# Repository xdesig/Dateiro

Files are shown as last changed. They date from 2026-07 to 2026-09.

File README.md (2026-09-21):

# Dateiro - Datalogger e visualización
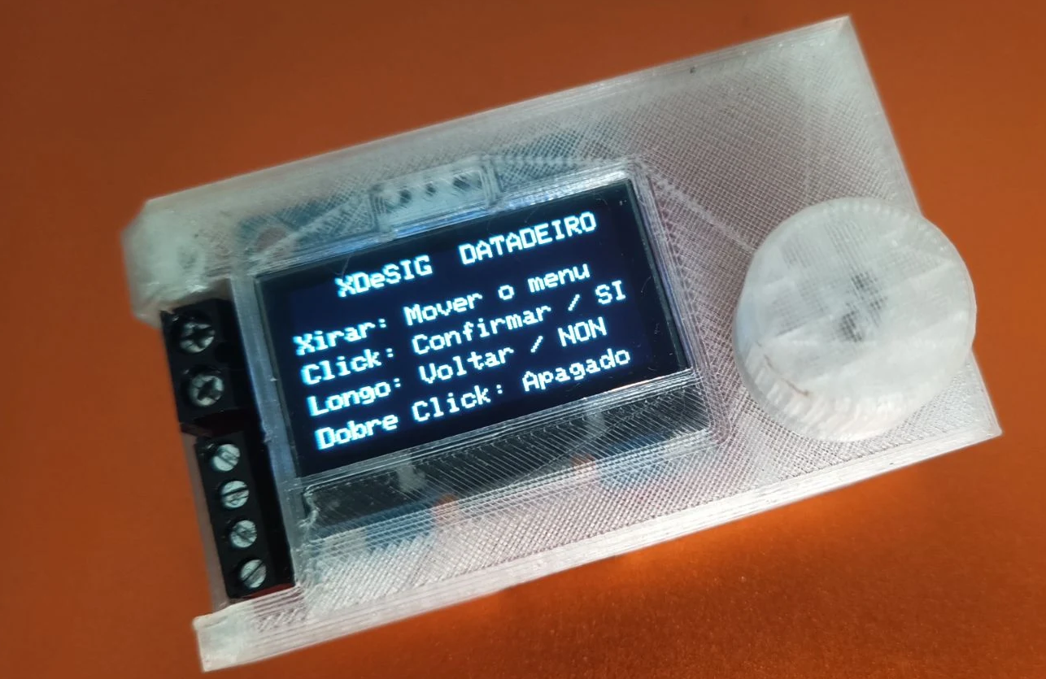
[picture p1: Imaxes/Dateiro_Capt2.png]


> [!NOTE]
> Documentation in Galego 
> [traductor](https://tradutorgaio.xunta.gal/TradutorPublico/traducir/index)

**Dateiro** e un sistema de adquisicion, visualizacion e rexistro de datos (datalogger) deseñado arredor do microcontrolador **ESP32-C3 SuperMini**.
O dispositivo permite a medicion de voltaxe diferencial, corrente e voltaxe de bus, mostrando un grafico en tempo real (modo osciloscopio) nunha pantalla e almacenando os datos en ficheiros `.CSV`
dentro duna tarxeta MicroSD.

---

## Caracteristicas do Firmware

### 1. Gráfica en Tempo Real
- **Buffer Circular:** Mantén un historico de 128 puntos para debuxar a onda na pantalla OLED a intervalos de 50ms (refresh de 20 Hz).
- **Escalado e Grade:** Debuxo de grade de puntos para escala visual e axuste automatico de rango (hasta 16V en modo diferencial e ata 1000mA en modo INA219).

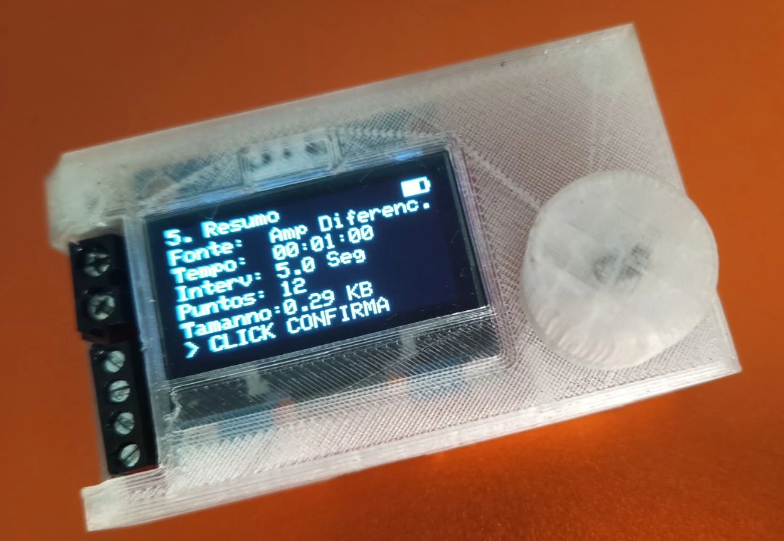
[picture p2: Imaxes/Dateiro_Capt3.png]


### 2. Datalogger Automático (Ficheiros CSV)
- **Nomenclatura Automática:** Crea ficheiros secuenciais no directorio raiz da tarxeta SD (`/DAT_001.CSV`, `/DAT_002.CSV`, etc.).
- **Modos de Mostraxe:**
  - **Por Intervalo:** Define o tempo entre mostras en segundos (ex: cada 5s).
  - **Por Cantidade de Puntos:** Distribue un numero fixo de puntos ao longo do tempo total configurado.
- **Formato do CSV:** Encabezado dinamico dependendo da orixe de datos (`Tempo_ms,Diferencial_V` ou `Tempo_ms,Corrente_mA`).

### 3. Navegación
- Interface baseada nun **Encoder Rotatorio** con descodificacion por matriz de estados (anti-rebotes por interruptor de hardware/software).
- **Xestion de Clicks:**
  - **Click Curto (>50ms):** Confirmar / Avanzar menu.
  - **Click Longo (>600ms):** Voltar / Cancelar / Deter gravacion.
  - **Dobre Click (<400ms):** Menu de apagado rapido.

### 4. Xestión de Enerxía e Deep Sleep
- **Lendo Batería:** Indicador de bateria con icono grafico na barra superior calculando o nivel mediante o pin `MVBAT` e detectando se esta en carga polo pin `STAT`.
- **Modo Apagado (Deep Sleep):** Apaga a pantalla OLED mediante comandos I2C (`0xAE`) e pon o ESP32-C3 en modo de soño profundo, incluida a OLED.
- **Despertado por Hardware:** Configura o pin do encoder (`PIN_ENC_B` / GPIO5) para espertar o sistema ao xirar o mando.

---

## Asignación de Pins (ESP32-C3 SuperMini)

| GPIO | Rede / Sinal | Descricion |
| :---: | :--- | :--- |
| **GPIO0** | `MOSI` | Bus SPI (Tarxeta SD) |
| **GPIO1** | `MVBAT` | Medicion de voltaxe da Bateria (Factor 1.816) |
| **GPIO2** | `MISO` | Bus SPI (Tarxeta SD) |
| **GPIO3** | `CS` | Chip Select SPI (Tarxeta SD) |
| **GPIO4** | `MEDV` | Entrada Analoxica Amplificada (LMC7101) |
| **GPIO5** | `ENC_B` | Encoder Rotatorio - Canle B (Wakeup GPIO) |
| **GPIO6** | `REG_EN` | Habilitacion do Regulador de Tensión |
| **GPIO7** | `ENC_A` | Encoder Rotatorio - Canle A |
| **GPIO8** | `STAT` | Estado da carga de Bateria (MCP73831) |
| **GPIO9** | `ENC_S` | Pulsador do Encoder Rotatorio |
| **GPIO10**| `CLK` | Reloxo Bus SPI (Tarxeta SD) |
| **GPIO20**| `SDA` | Bus I2C (OLED SH1106 + INA219) |
| **GPIO21**| `SCL` | Bus I2C (OLED SH1106 + INA219) |

---

## Librarías Requiridas

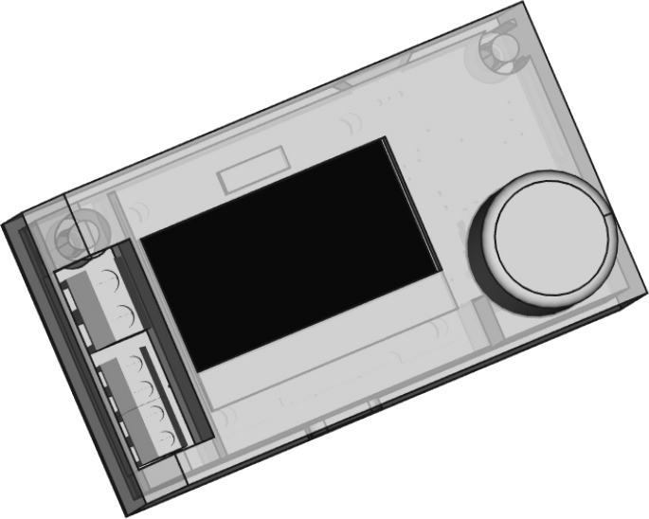
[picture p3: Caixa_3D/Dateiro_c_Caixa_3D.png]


Para compilar este proxecto na IDE de Arduino ou PlatformIO, precísanse as seguintes librarías:

- `Wire.h` e `SPI.h` (Incluídas no core de ESP32)
- `SD.h` (Incluída no core de ESP32)
- [Adafruit_GFX](https://github.com/adafruit/Adafruit-GFX-Library)
- [Adafruit_SH110X](https://github.com/adafruit/Adafruit_SH110X) (Para pantallas OLED SH1106G)
- [Adafruit_INA219](https://github.com/adafruit/Adafruit_INA219)

---

## Bill of Materials (BOM)

| Qty | Value / Component | Footprint / Package | Designator | Description |
| :---: | :--- | :--- | :--- | :--- |
| **2** | 10uF | C0603 | `C1`, `C3` | Capacitor |
| **1** | 100nF | C0603 | `C2` | Capacitor |
| **1** | SS14 | SOD-323 | `D1` | Diodo Schottky |
| **1** | Conn_01x02 | PinHeader 1x02 (2.54mm) | `J1` | Conector |
| **2** | Conn_01x04 | PinHeader 1x04 (2.54mm) | `J2`, `J3` | Conector |
| **1** | S8050 | SOT-23 | `Q1` | Transistor NPN |
| **4** | 10k | R0603 | `R1`, `R2`, `R4`, `R5` | Resistencia |
| **1** | 1k | R0603 | `R3` | Resistencia |
| **1** | SW_Push | 4.5x4.5mm | `SW1` | Pulsador |
| **1** | ESP32-C3-SuperMini | Board / Module | `U1` | Modulo Microcontrolador ESP32-C3 |
| **1** | HX711 | Module | `U2` | Modulo Amplificador Celula de Carga |
| **1** | DS1307 | SOP-8 | `U3` | Reloxo en Tempo Real (RTC) |
| **1** | 32.768kHz | Crystal D2.0mm L6.0mm | `Y1` | Cristal Oscilador RTC |

---
- Deseñado en Extrimia con agarimo.



- Saudos.

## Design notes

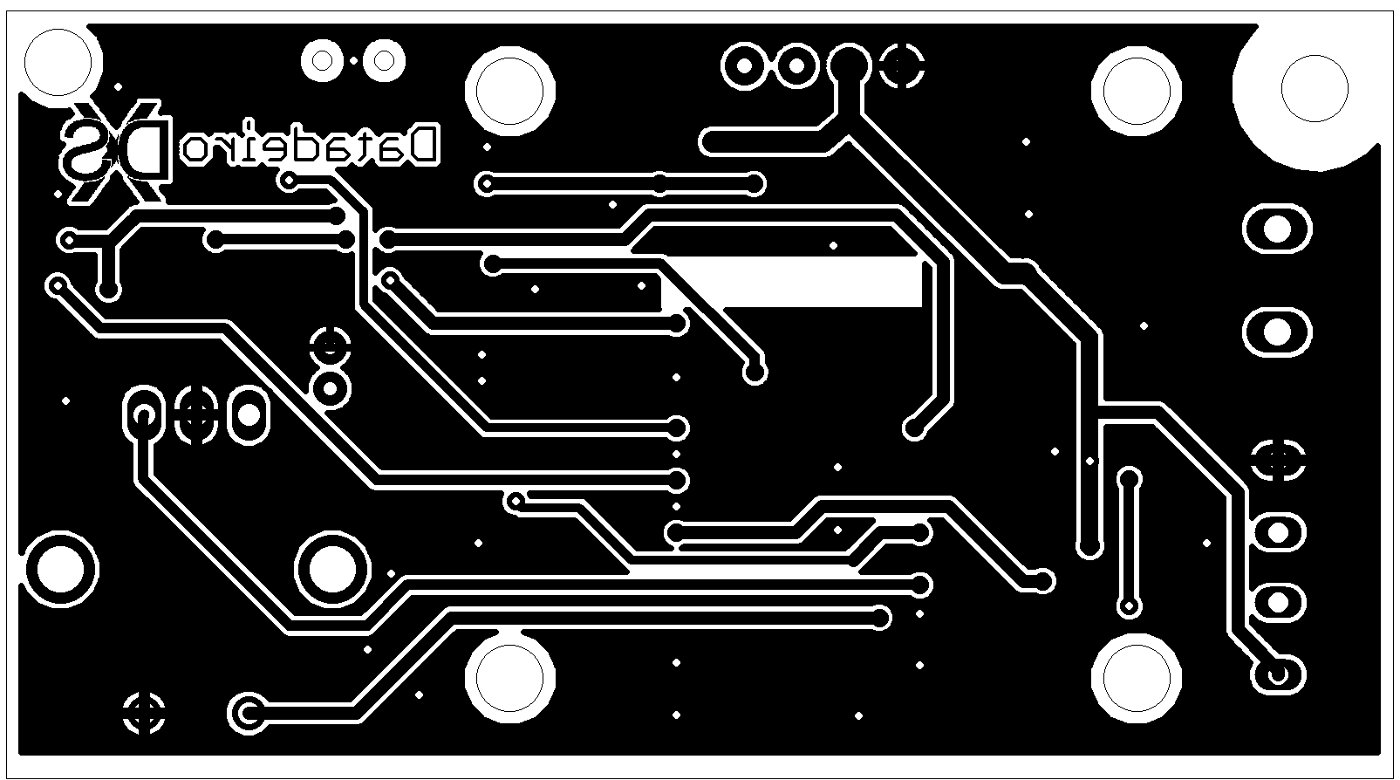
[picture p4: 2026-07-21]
Electronica/MED_ESP32_C3_0002_BOT.png

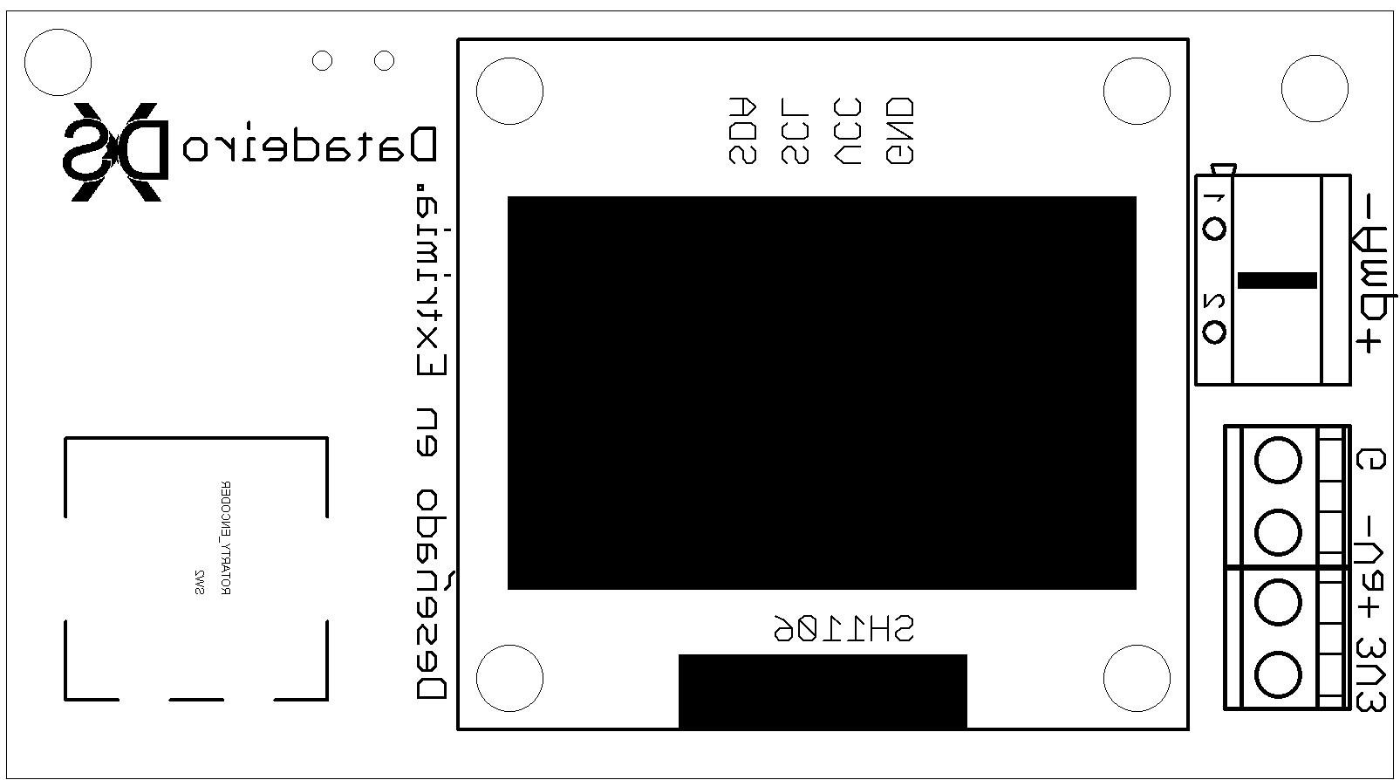
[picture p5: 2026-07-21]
Electronica/MED_ESP32_C3_0002_SilkBot.png

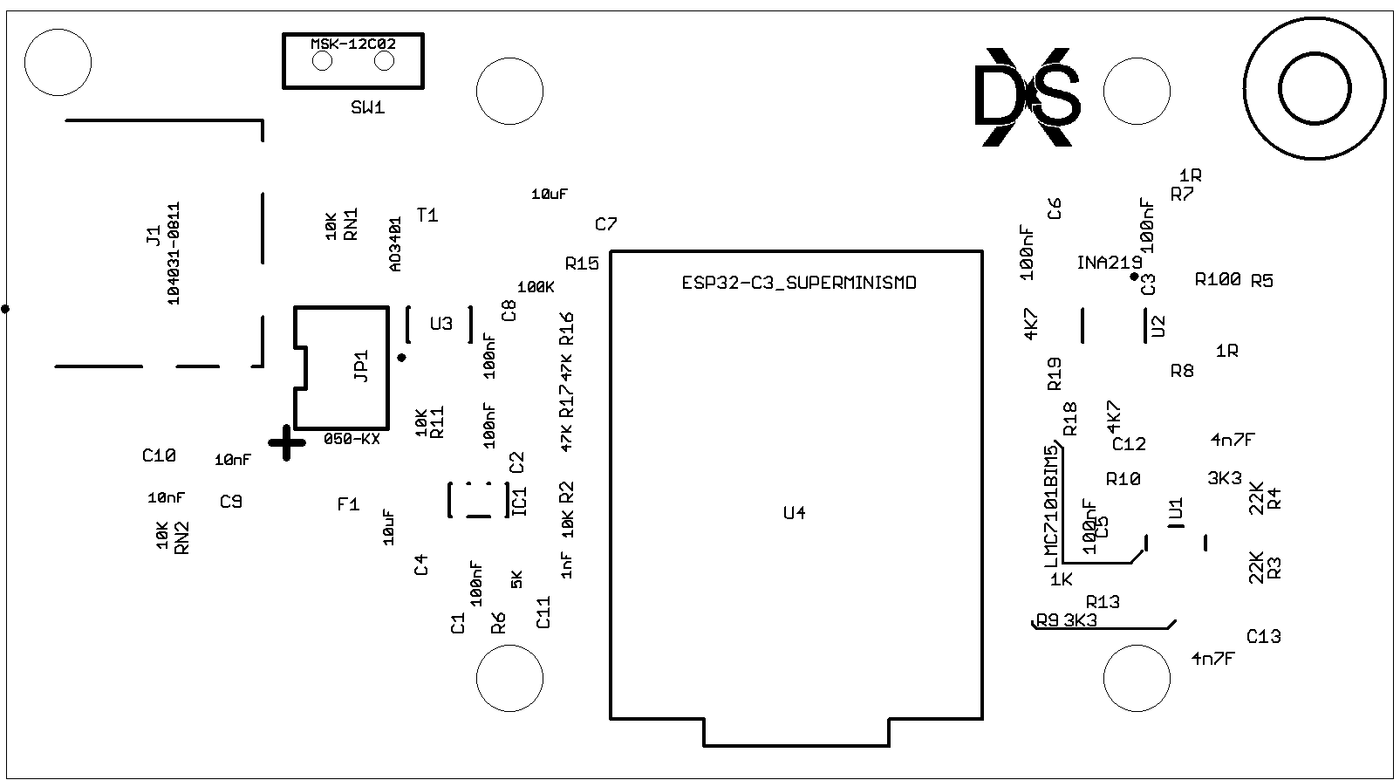
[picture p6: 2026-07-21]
Electronica/MED_ESP32_C3_0002_SilkTop.png

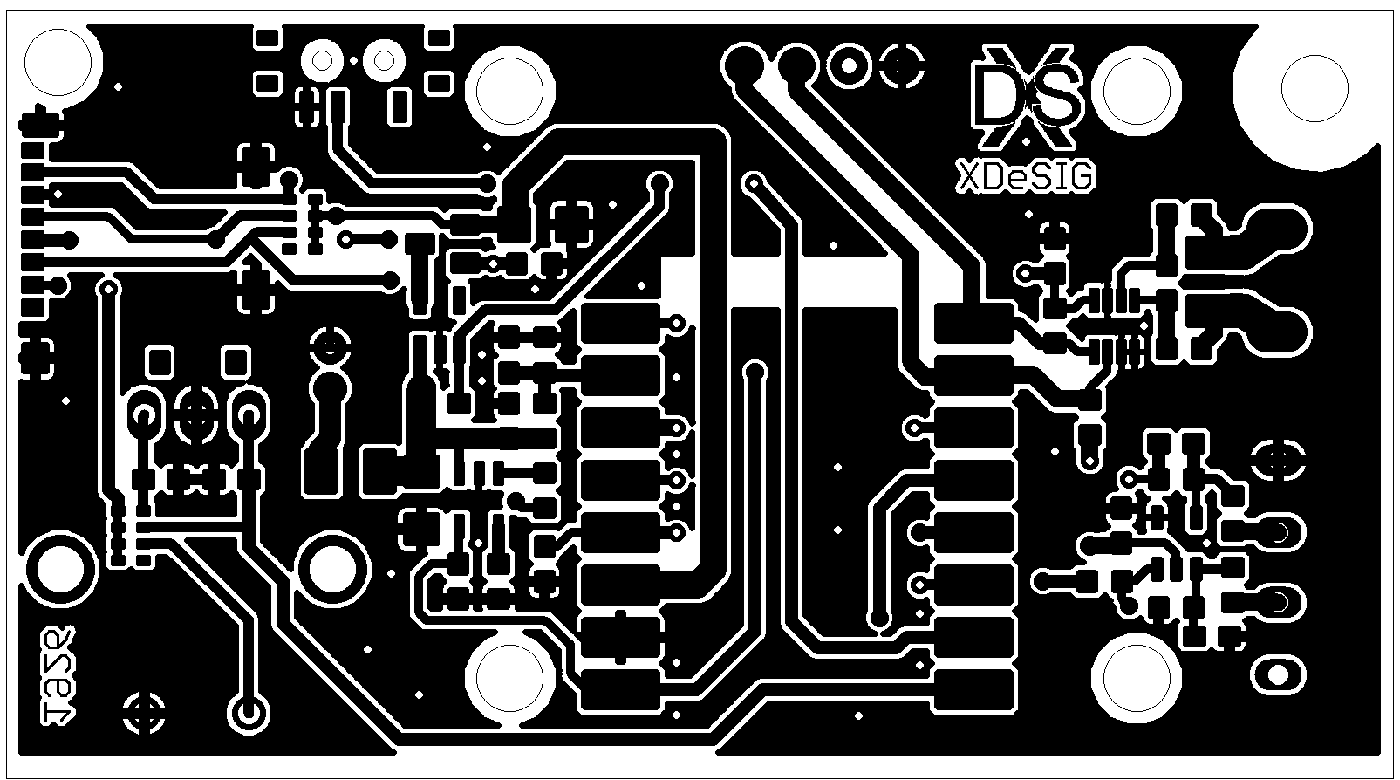
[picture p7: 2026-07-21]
Electronica/MED_ESP32_C3_0002_TOP.png

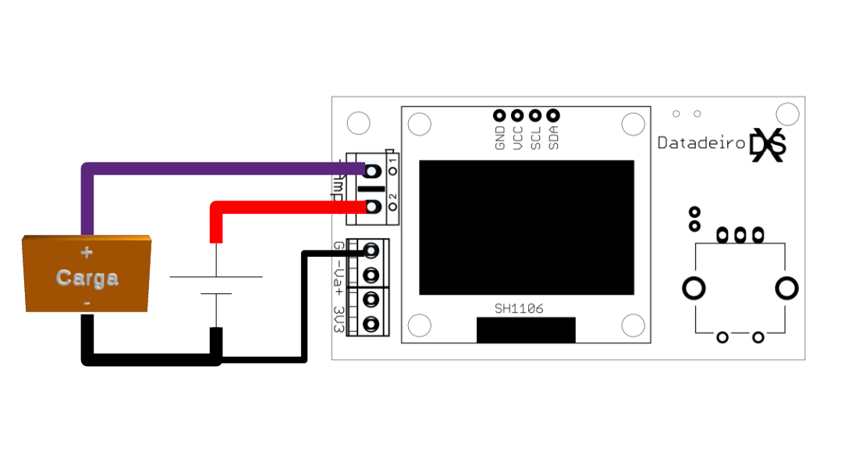
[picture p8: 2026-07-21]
Imaxes/MedidaDeCorrente_pot.png

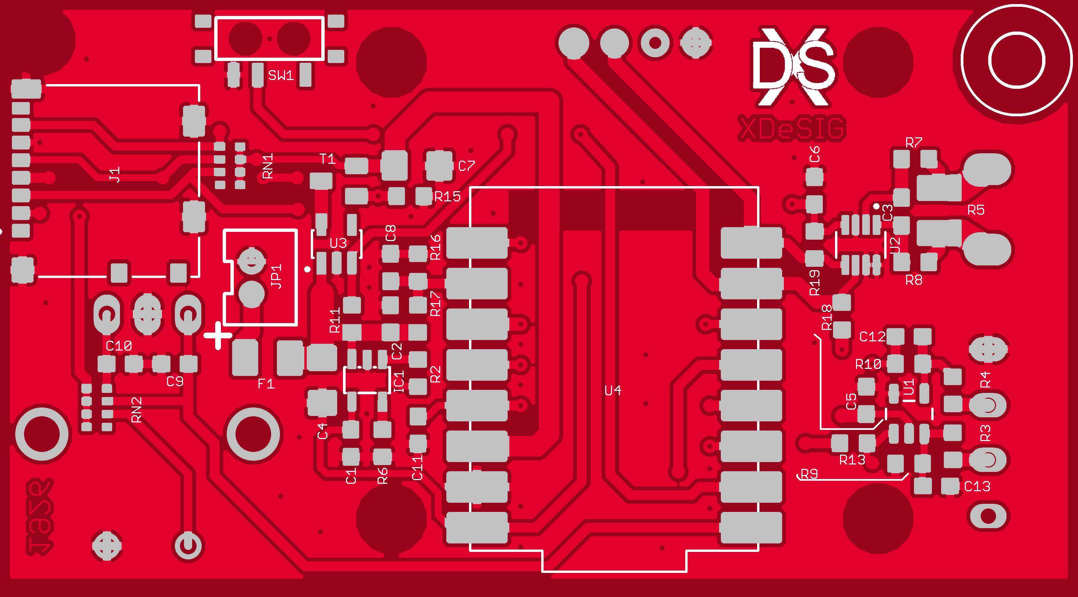
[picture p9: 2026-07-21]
Imaxes/eagleUp_MED_ESP32_C3_0002_board_top.png

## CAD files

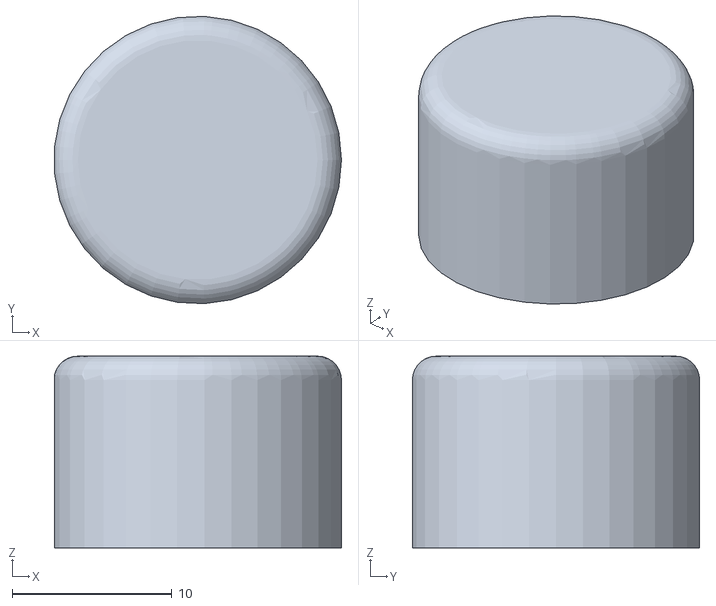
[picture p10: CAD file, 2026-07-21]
Caixa_3D/MED_ESP32_C3_Mando.stl
18.0 x 18.0 x 12.0

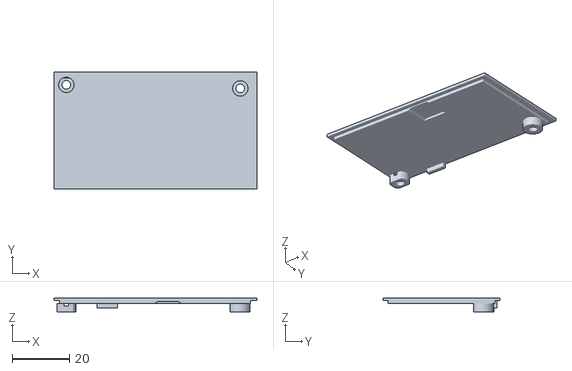
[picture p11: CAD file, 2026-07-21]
Caixa_3D/MED_ESP32_C3_Tapa.stl
71.2 x 41.2 x 5.00

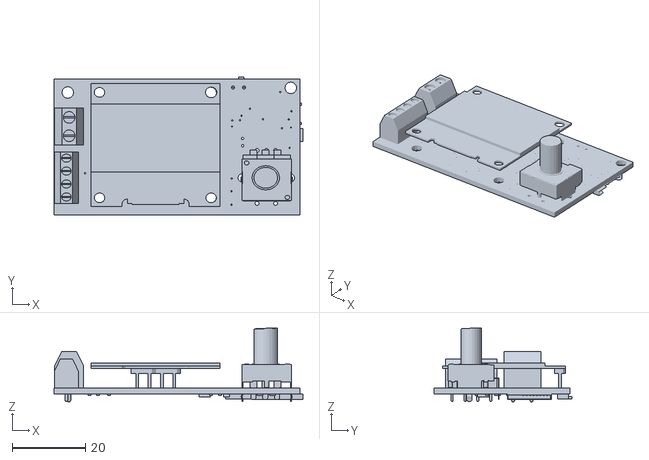
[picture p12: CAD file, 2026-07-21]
Caixa_3D/MED_ESP32_C3_0002.stl
68.1 x 37.8 x 20.2

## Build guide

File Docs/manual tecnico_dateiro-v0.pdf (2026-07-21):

DATEIRO
DOCUMENTACIÓN TÉCNICA DE HARDWARE E FIRMWARE • REV 002
1. Descrición xeral do sistema
O Dateiro é un dispositivo electrónico autónomo deseñado para a monitorización, rexistro (datalogging) e visualización de variables eléctricas en tempo real. Permite medir tensións externas de ata 20V (cun rango óptimo recomendado menor ou igual a 16.5V) e correntes mediante shunt integrado. Os datos recollidos visualízanse nunha pantalla OLED de 1.3", almacénanse nunha tarxeta MicroSD mediante o bus SPI e a navegación polo sistema realízase a través dun encoder rotatorio multifunción.

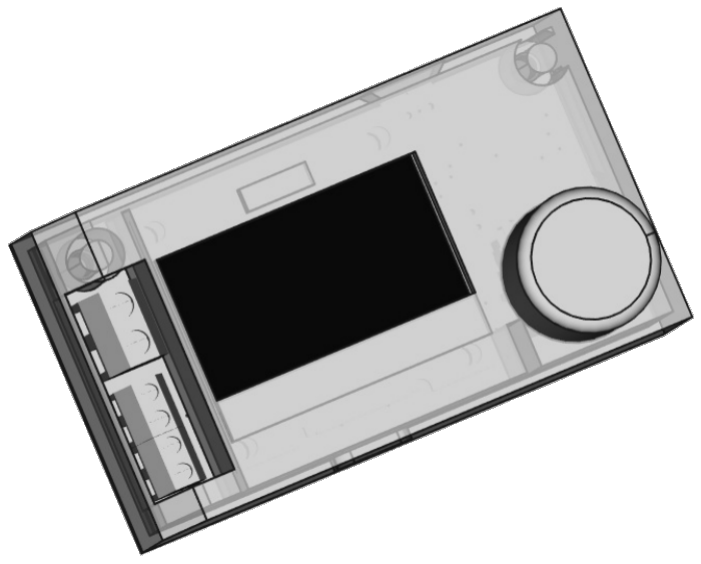
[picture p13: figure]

2. Especificacións técnicas
Rango de medida V diferencial: Máximo de 20V (Límite lineal recomendado: 16.5V). Rango de medida l/V: Máximo de 3A e 26V (-amp) con respecto a GND
Procesador: Microcontrolador ESP32-C3 RISC-V de 32 bits (Módulo SuperMini). Alimentación externa: Entrada de 5V DC regulada vía porto USB (Módulo SuperMini). Alimentación autónoma: Circuíto compatible con batería de LiPo (3.7V nominal). Interface de usuario: Pantalla OLED de 1.3" (Controlador SH1106 / Interface I2C) e Encoder Rotatorio con pulsador integrado.
Almacenamento: Ranura MicroSD conectada por bus SPI dedicado.
3. Asignación de Pines e Periféricos (Hardware vs. Software)
A seguinte táboa especifica de forma unívoca a correspondencia entre os nodos físicos identificados no esquema do circuíto (MED_ESP32_C3_0002_SCH.pdf) e as definicións de macros imprementadas no firmware operativo do sistema (Dateiro.ino):

DOCUMENTACIÓN TÉCNICA DE HARDWARE E FIRMWARE • REV 002

in ESP32-C3 | Sinal | Periférico asociado | Descrición funcional
GPIO0 | PIN_SD_MOSI | Slot MicroSD (104031-0811) | Saída de datos SPI
GPIO1 | PIN_MVBAT | Divisor de tensión LiPo | Entrada analóxica para monitorizar a batería
GPIO2 | PIN_SD_MISO | Slot MicroSD (104031-0811) | Entrada de datos SPI
GPIO3 | PIN_SD_CS | Slot MicroSD (104031-0811) | Chip Select do bus SPI
GPIO4 | PIN_MEDV | Amp. Op. LMC7101BIM5 | Entrada analóxica - Medida de tensión (Vmedida)
GPIO5 | PIN_ENC_B | Encoder Rotatorio (SW2) | Canle B do encoder (interrupción)
GPIO6 | PIN_REG_EN | Habilitación Regulador/Siste ma | Control de enerxía
GPIO7 | PIN_ENC_A | Encoder Rotatorio (SW2) | Canle A do encoder (interrupción)
GPIO8 | PIN_STAT | Cargador MCP73831/2 | Estado de carga da batería (LED D6)
GPIO9 | PIN_ENC_S | Pulsador do Encoder (SW2) | Entrada dixital de control de interface
GPIO10 | PIN_SD_CLK | Slot MicroSD (104031-0811) | Reloxo de bus SPI
GPIO20 | PIN_SDA_I2C | Pantalla OLED / | Liña de datos I2C (Pull-ups 4K7

DOCUMENTACIÓN TÉCNICA DE HARDWARE E FIRMWARE • REV 002

in ESP32-C3 | Sinal | Periférico asociado | Descrición funcional
| | INA219 | externos)
GPIO21 | PIN_SCL_I2C | Pantalla OLED / INA219 | Liña de reloxo I2C (Pull-ups 4K7 externos)

DOCUMENTACIÓN TÉCNICA DE HARDWARE E FIRMWARE • REV 002

4. Arquitectura de hardware e bloques funcionais
A. Bloque de alimentación e carga

O deseño garante a autonomía do sistema integrando un cargador lineal de baterías de ión de litio IC1 (MCP73831/2), alimentado dende a liña de 5V extraída do (Módulo SuperMini). O pin de estado STAT conéctase ao GPIO8. O regulador (LDO) U3 (AP2112K-3.3TRG1) reduce a tensión da batería LiPo a un nivel estable de 3.3V requirido polo microcontrolador e os compoñentes dixitais. Un transistor MOSFET de canle P T1 (AO3401) implementa unha conmutación de potencia automática e segura entre as dúas fontes, mentres que o interruptor mecánico deslizante SW1 (MSK-12C02) permite a deshabilitación do U3.

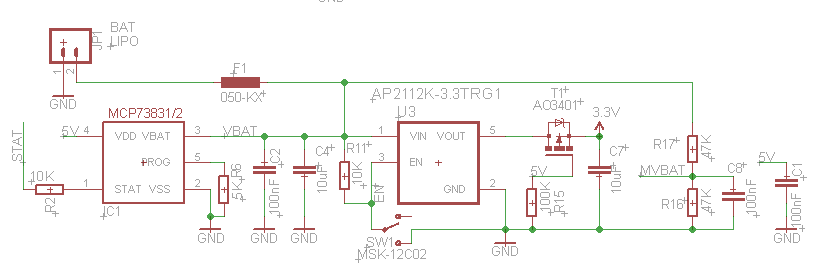
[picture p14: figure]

B. Entradas de medida analóxicas / dixitais.

O circuíto permite a adquisición de magnitudes a través de dous métodos ben diferenciados e seleccionables dende o menú de configuración:

- Canle de Tensión Diferencial: Emprega un amplificador operacional en configuración de amplificador diferencial U1 (LMC7101B). Este bloque introduce unha atenuación calibrada para mapear de forma lineal os 20V máximos de entrada a valores asimilables polo ADC (0 – 3.3V). (Cun rango óptimo recomendado ≤ 16.5V)
- NOTA DE CALIBRACIÓN
POR SOFTWARE:
O algoritmo imprementado
para a canle diferencial
corrixe o desvío intrínseco de

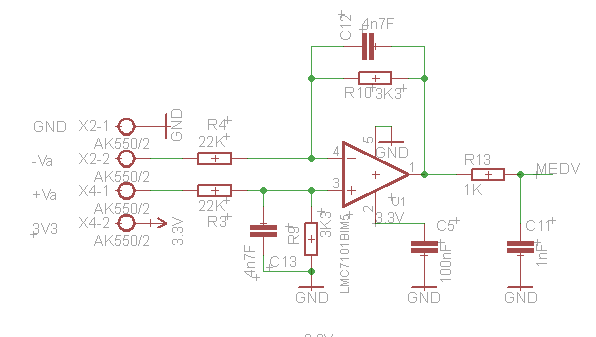
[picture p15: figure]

compoñentes aplicando unha ecuación lineal de axuste: novoValor = (VmedvLocal -
VOFFSET_ZERO) /
GANANCIA_REAL
Onde o offset de cero está fixado en 0.021V e a ganancia real sitúase en 0.150

DOCUMENTACIÓN TÉCNICA DE HARDWARE E FIRMWARE • REV 002

- Amperímetro/ Voltímetro (INA219): O circuíto integrado U2 conéctase de xeito directo ao bus I2C (dirección hardware por defecto 0x40) e monitoriza a caída de tensión diferencial producida a través da resistencia shunt de precisión R100 de 0.1Ω.
Tamén podemos medir a tensión entre a entrada “- Amp” e GND obtendo así a potencia disipada na carga.

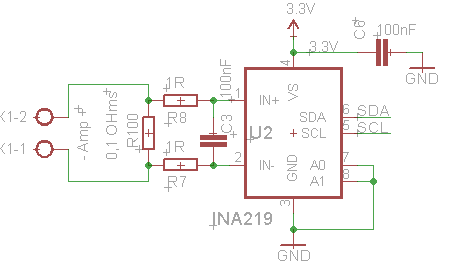
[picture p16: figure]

DOCUMENTACIÓN TÉCNICA DE HARDWARE E FIRMWARE • REV 002

5. Algoritmo do firmware e interface de usuario (FSM)
O programa principal está estruturado sobre unha Máquina de Estados Finitos (FSM) robusta que impide bloqueos e xestiona con precisión a navegación do usuario a través do movemento do encoder:
- E_PRINCIPAL: Pantalla por defecto. Amosa as lecturas actuais e o estado do sistema.
- E_MENU_ORIXE: Selección da fonte de datos activa (0: Amplificador diferencial, 1: Sensor INA219).
- E_MENU_HORAS / E_MENU_MINUTOS / E_MENU_SEGUNDOS: Configuración do tempo total planificado para o rexistro de datos.
- E_MENU_METODO: Elección da estratexia de mostraxe (definida por número total de puntos ou por intervalo de tempo estables).
- E_MENU_VALOR: Introdución cuantitativa dos parámetros seleccionados no paso anterior.
- E_MENU_RESUMO: Mostra o resumo detallado da sesión programada (puntos totais, intervalo resultante, estimación do peso do ficheiro en KB) e agarda a confirmación para iniciar.
- E_GRAVANDO: Modo activo de adquisición. Executa tarefas de visualización gráfica en tempo real, mostraxe temporizada e garda cíclica no arquivo MicroSD.
- E_FIN_GRAVACION: Pantalla de finalización exitosa co nome do arquivo xerado.

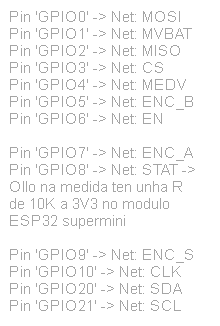
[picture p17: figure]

DOCUMENTACIÓN TÉCNICA DE HARDWARE E FIRMWARE • REV 002

6. Xestión de pulsacións (Filtro antirebotes)
A rutina non bloquéante lerBoton() avalía de forma dinámica a duración do impulso mecánico para desencadear tres tipos de accións específicas:
- Click Curto (50ms a 600ms): Valida a opción seleccionada e avanza ao estado consecutivo da FSM.
- Click Longo (>600ms): Cancela a acción actual ou efectúa un retroceso controlado cara ao menú anterior.
- Dobre Click (intervalo entre pulsacións <400ms): Na pantalla principal para a desconexión segura do dispositivo (E_APAGAR).

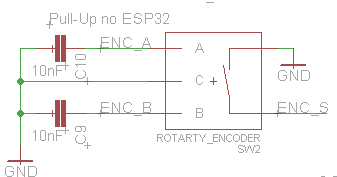
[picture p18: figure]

DOCUMENTACIÓN TÉCNICA DE HARDWARE E FIRMWARE • REV 002

7. Sistema de almacenamento (Datalogger)

Ao iniciarse a gravación no estado E_GRAVANDO, o firmware realiza unha secuencia estrita de control sobre o sistema de ficheiros:

- Detección Automatizada: Verifica a correcta inicialización do hardware MicroSD mediante o comando SD.begin(PIN_SD_CS). En caso de ausencia da tarxeta, aborta o proceso de forma segura notificando o erro na pantalla.
- Prevención de sobrescrita: Executa un algoritmo de indexación secuencial automático que busca na raíz da tarxeta un espazo baleiro libre, xerando arquivos correlativos con formato ordenado desde /DAT_001.CSV ata un máximo de /DAT_999.CSV.
- Integridade de datos: Trala inxección de cada nova mostra de datos estruturados mediante o comando ficheiroDatos.printf(), o firmware executa inmediatamente un método ficheiroDatos.flush(). Esta operación forza o baleirado do buffer de memoria do ESP32-C3 directamente ao soporte físico, minimizando o risco de perda ou corrupción de datos ante un esgotamento ou desconexión imprevista da batería.

DOCUMENTACIÓN TÉCNICA DE HARDWARE E FIRMWARE • REV 002

8. Modo de baixo consumo (Deep Sleep) e desconexión

Cando o sistema entra no estado de apagado ordenado, estender a autonomía da batería LiPo.

O envío do comando 0xAE á pantalla OLED desactiva o xerador de carga interno da pantalla, reducindo a cero a excitación dos píxeles orgánicos. De seguido, illase o microcontrolador ESP32-C3 detendo os seus núcleos de procesamento e reloxos internos. O dispositivo permanece nun estado de consumo de microamperes (Deep Sleep) ata que o usuario xera un pulso flanco descendente ao mover mecanicamente o encoder rotatorio a través da liña PIN_ENC_B, espertando instantaneamente o sistema sen necesidade dun botón de reset adicado.

DOCUMENTACIÓN TÉCNICA DE HARDWARE E FIRMWARE • REV 002

9. Conexionado

Bloque de Entradas de Medida [-] Amp [+]

Estes terminais conéctanse directamente ao sensor de corrente INA219.

-Amp (Terminal superior): Conéctase á saída negativa do sensor de corrente.

+Amp (Terminal inferior): Conéctase á entrada positiva do sensor de corrente.

Función: A través destes dous puntos monitorízase a caída de tensión na resistencia shunt de 0.1W para calcular a corrente e, medindo respecto a GND, a potencia disipada.

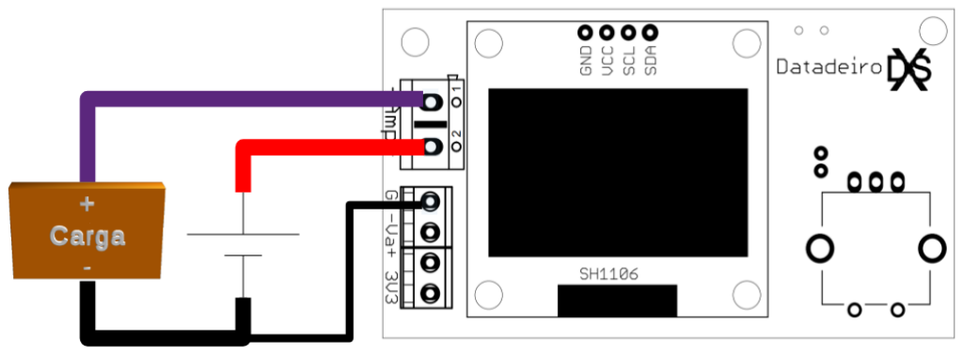
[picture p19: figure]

Sé so se precisa medir corrente, non é preciso a conexión a GND.

Bloque de Entradas de Medida de Tensión [G] [-] Va [+] [3V3]

Este conector xestiona a alimentación externa e a medida de tensión diferencial a través do amplificador operacional LMC7101B.

G (GND): Masa común do sistema.

-Va: Entrada negativa do amplificador diferencial.

+: Entrada positiva do amplificador diferencial.

3V3: Saída regulada de 3.3V, útil para alimentar pequenos sensores externos ou circuítos auxiliares (non usar para alimentar o sistema principal).

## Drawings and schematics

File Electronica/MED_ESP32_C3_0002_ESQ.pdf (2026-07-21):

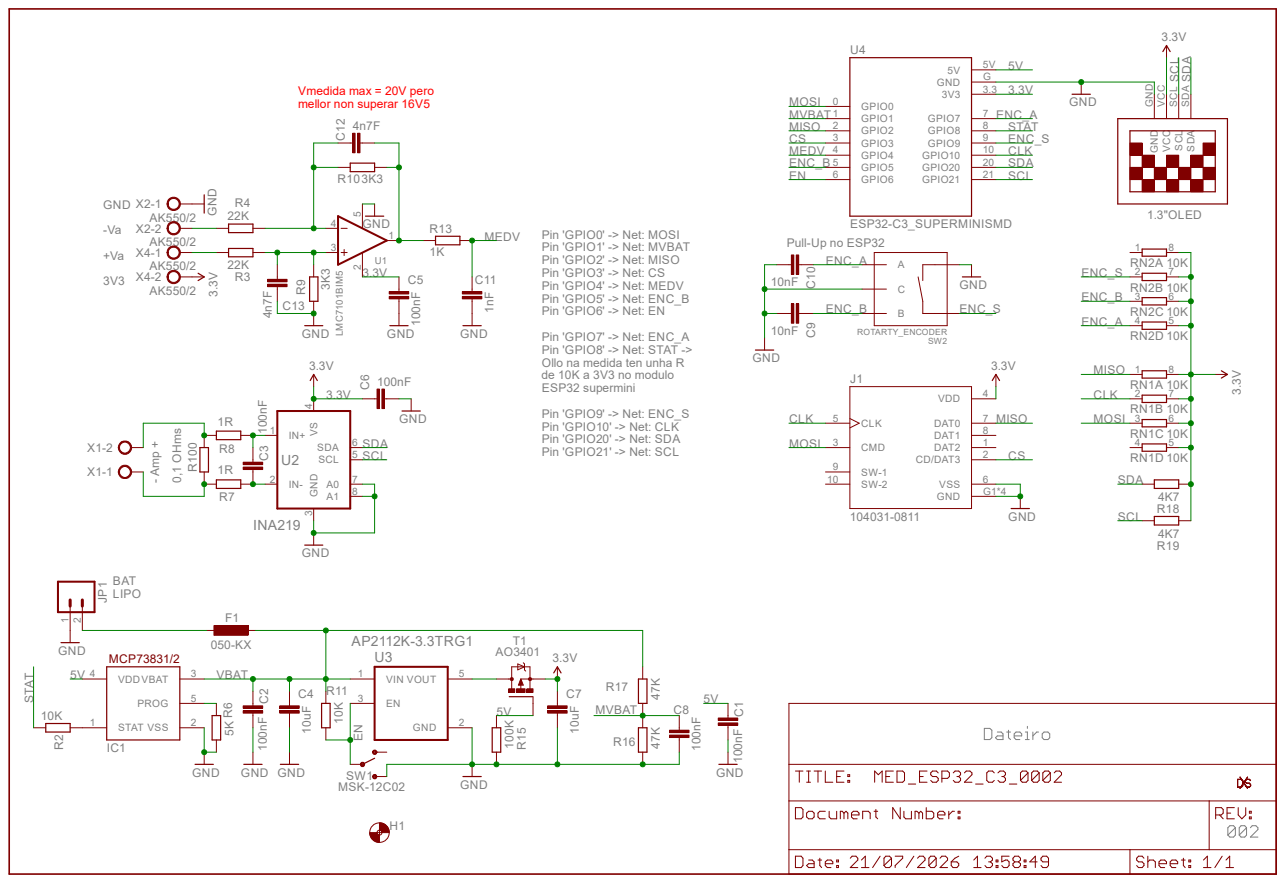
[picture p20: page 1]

Pin 'GPIO0' -> Net: MOSI
Pin 'GPIO1' -> Net: MVBAT
Pin 'GPIO2' -> Net: MISO
Pin 'GPIO3' -> Net: CS
Pin 'GPIO4' -> Net: MEDV
Pin 'GPIO5' -> Net: ENC_B
Pin 'GPIO6' -> Net: EN
Pin 'GPIO7' -> Net: ENC_A
Pin 'GPIO8' -> Net: STAT ->
Ollo na medida ten unha R
de 10K a 3V3 no modulo
ESP32 supermini

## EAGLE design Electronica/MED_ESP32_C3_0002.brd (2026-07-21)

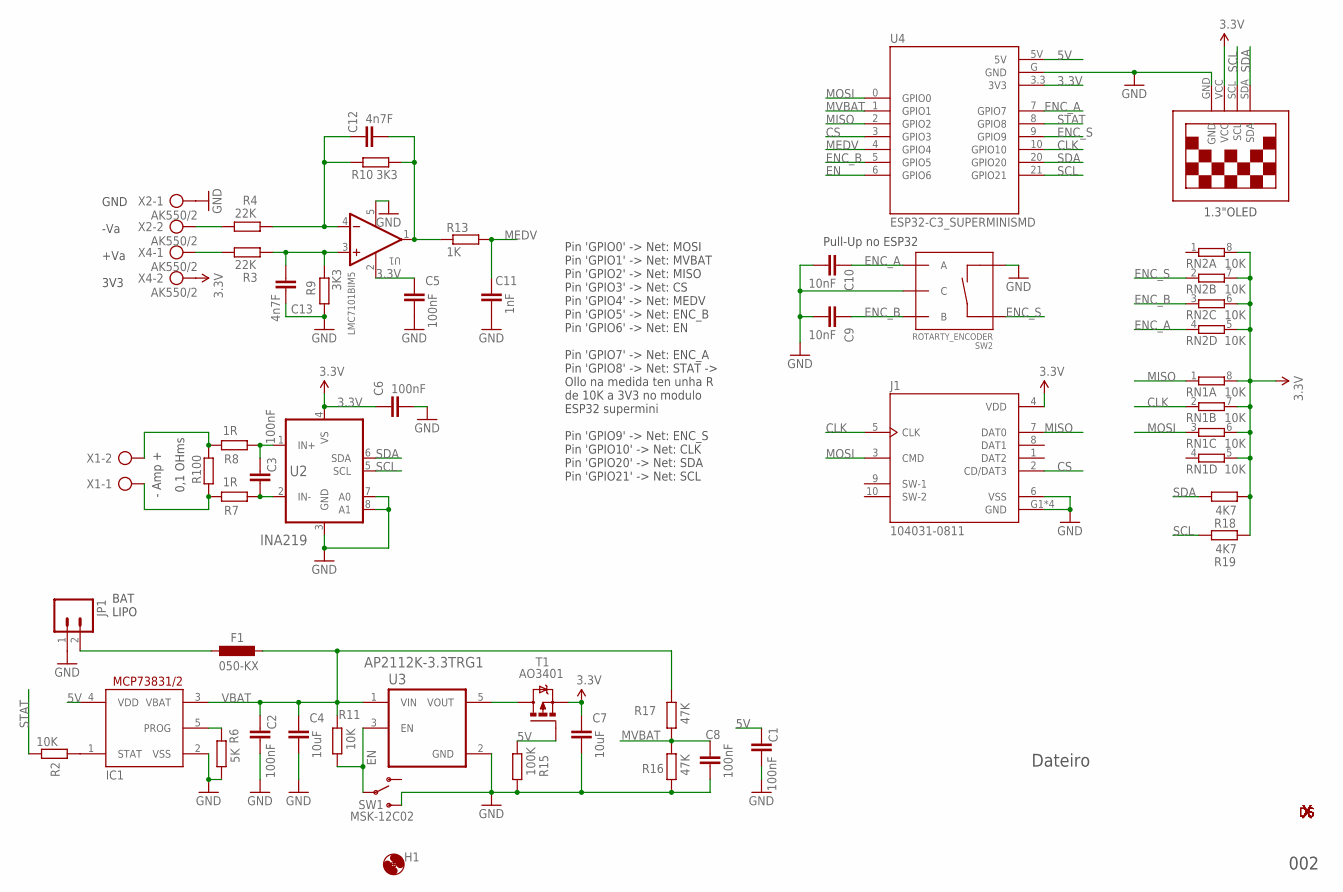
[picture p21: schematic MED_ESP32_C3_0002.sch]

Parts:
C1, C2, C3, C5, C6, C8: 100nF; C0603
C4, C7: 10uF; C1206
C9, C10: 10nF; C0603
C11: 1nF; C0603
C12, C13: 4n7F; C0603
F1: 050-KX; L3225M
H1: HOLES_MOUNT-HOLE3.2; HOLES_3,2
IC1: MCP73831T-2; SOT23-5L
J1: 104031-0811; MOLEX_104031-0811
JP1: M02JST-PTH-VERT; JST-2-PTH-VERT
R2, R11: 10K; R0603
R3, R4: 22K; R0603
R5: R100; R1210
R6: 5K; R0603
R7, R8: 1R; R0603
R9, R10: 3K3; R0603
R13: 1K; R0603
R15: 100K; R0603
R16, R17: 47K; R0603
R18, R19: 4K7; R0603
RN1: 10K; RESISTOR-DIL_0603-ARC
RN2: 10K; RESISTOR-DIL_0603-ARV
SW1: MSK-12C02; KPS-1290
SW2: ROTARTY_ENCODER; ROTARY_ENC_PLAIN
T1: AO3401; SOT23
U1: LMC7101BIM5; SOT95P280X145-5N
U2: INA219; SOT65P280X145-8N
U3: AP2112K-3.3TRG1; SOT95P285X140-5N
U4: ESP32-C3_SUPERMINISMD; MODULE_ESP-C3_SUPERMINI_SMD
U$1: 13"OLED13"OLED; 1.3"OLED
U$2, U$5: XDESIG5MM; XDESIG_CU
U$3, U$4: XDESIG21; XDESIG
X1: AK500/2
X2, X4: AK550/2

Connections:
3.3V: C5.2, C6.2, C7.2, J1.4 (VDD), R18.2, R19.2, RN1.5 (2), RN1.6 (2), RN1.7 (2), RN1.8 (2), RN2.5 (2), RN2.6 (2), RN2.7 (2), RN2.8 (2), T1.2 (S), U1.2 (V+), U2.4 (VS), U4.3.3 (3V3), U$1.VCC, X4.2
5V: C1.1, IC1.4 (VDD), R15.2, T1.1 (G), U4.5V
CLK: J1.5 (CLK), RN1.2 (1), U4.10 (GPIO10)
CS: J1.2 (CD/DAT3), U4.3 (GPIO3)
EN: R11.1, SW1.P, U3.3 (EN), U4.6 (GPIO6)
ENC_A: C10.2, RN2.4 (1), SW2.A, U4.7 (GPIO7)
ENC_B: C9.2, RN2.3 (1), SW2.B, U4.5 (GPIO5)
ENC_S: RN2.2 (1), SW2.SW+, U4.9 (GPIO9)
GND: C1.2, C2.2, C4.1, C5.1, C6.1, C7.1, C8.2, C9.1, C10.1, C11.1, C13.2, IC1.2 (VSS), J1.6 (VSS), J1.G1 (GND), J1.G2 (GND), J1.G3 (GND), J1.G4 (GND), JP1.1, R6.1, R9.2, R15.1, R16.1, SW1.S, SW2.C, SW2.SW-, U1.5 (V-), U2.3 (GND), U2.7 (A0), U2.8 (A1), U3.2 (GND), U4.G (GND), U$1.GND, X2.1
MEDV: C11.2, R13.2, U4.4 (GPIO4)
MISO: J1.7 (DAT0), RN1.1, U4.2 (GPIO2)
MOSI: J1.3 (CMD), RN1.3 (1), U4.0 (GPIO0)
MVBAT: C8.1, R16.2, R17.1, U4.1 (GPIO1)
unnamed: R4.2, X2.2
unnamed: T1.3 (D), U3.5 (VOUT)
unnamed: C12.2, R4.1, R10.2, U1.4 (-IN)
unnamed: R3.2, X4.1
unnamed: IC1.1 (STAT), R2.2
unnamed: IC1.5 (PROG), R6.2
unnamed: C12.1, R10.1, R13.1, U1.1 (OUT)
unnamed: F1.2, JP1.2
unnamed: C13.1, R3.1, R9.1, U1.3 (+IN)
unnamed: C3.1, R8.2, U2.1 (IN+)
unnamed: C3.2, R7.2, U2.2 (IN-)
unnamed: R5.2, R8.1, X1.2
unnamed: R5.1, R7.1, X1.1
SCL: R19.1, U2.5 (SCL), U4.21 (GPIO21), U$1.SCL
SDA: R18.1, U2.6 (SDA), U4.20 (GPIO20), U$1.SDA
STAT: R2.1, U4.8 (GPIO8)
VBAT: C2.1, C4.2, F1.1, IC1.3 (VBAT), R11.2, R17.2, U3.1 (VIN)

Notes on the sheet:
0,1 OHms
BAT LIPO
Pull-Up no ESP32
002
Dateiro
1.3"OLED
Pin 'GPIO0' -> Net: MOSI Pin 'GPIO1' -> Net: MVBAT Pin 'GPIO2' -> Net: MISO Pin 'GPIO3' -> Net: CS Pin 'GPIO4' -> Net: MEDV Pin 'GPIO5' -> Net: ENC_B Pin 'GPIO6' -> Net: EN Pin 'GPIO7' -> Net: ENC_A Pin 'GPIO8' -> Net: STAT -> Ollo na medida ten unha R de 10K a 3V3 no modulo ESP32 supermini Pin 'GP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
GND -Va +Va 3V3
- Amp +

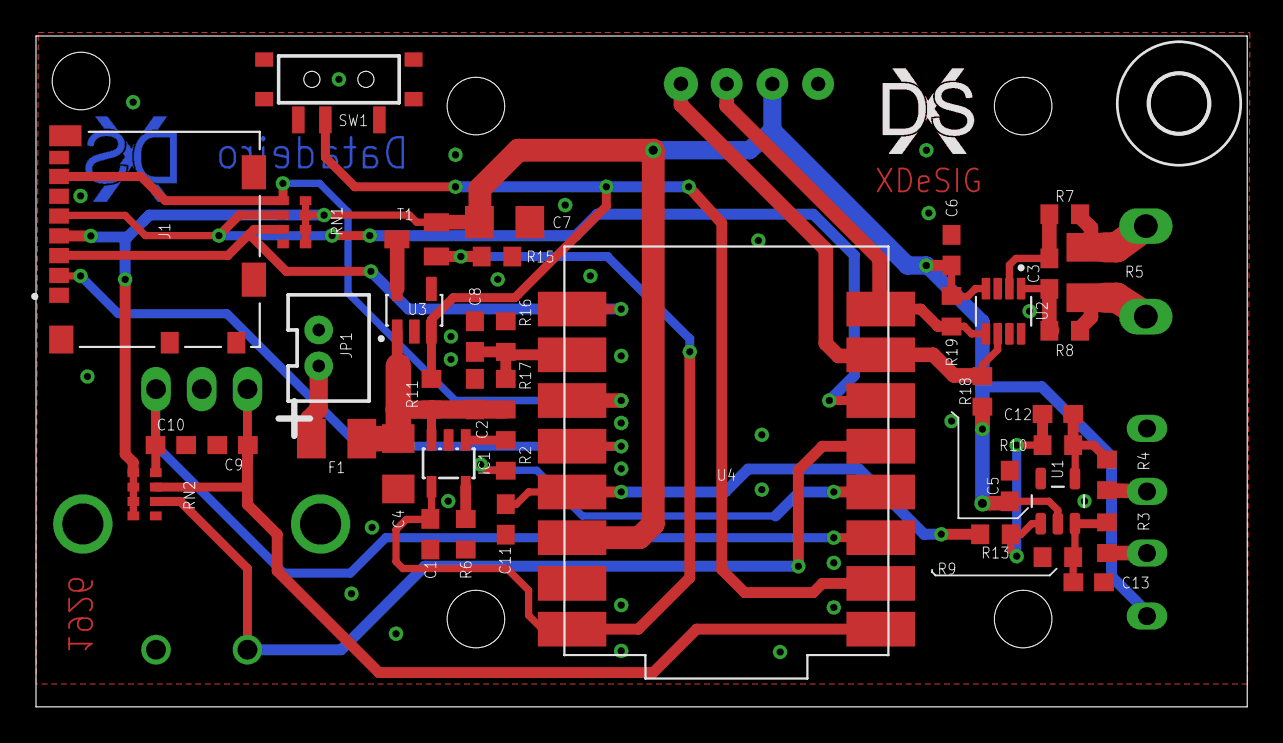
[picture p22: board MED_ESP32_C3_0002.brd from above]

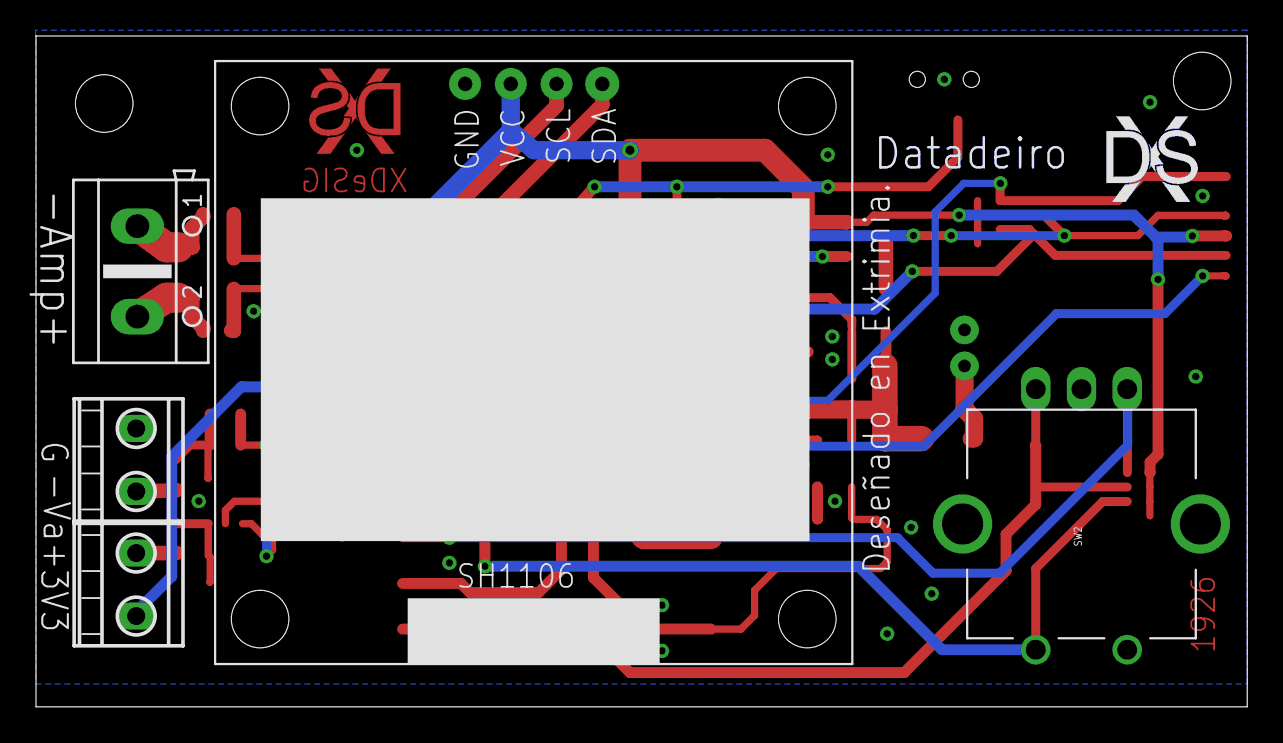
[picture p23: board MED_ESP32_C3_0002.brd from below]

Board: 2 copper layers, 67.3 x 37.3 mm, 51 parts (7 on the bottom side), 30 nets.

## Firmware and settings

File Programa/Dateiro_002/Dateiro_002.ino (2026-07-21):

/*  Dateiro V002 (XDeSIG 2026)
sistema de adquisicion, visualizacion e rexistro de datos (datalogger) deseñado arredor do microcontrolador **ESP32-C3 SuperMini**. 
O dispositivo permite a medicion de voltaxe diferencial, corrente e voltaxe de bus, mostrando un grafico en tempo real (modo osciloscopio) nunha pantalla 
e almacenando os datos en ficheiros `.CSV` dentro duna tarxeta MicroSD.
- Xestion de Clicks:
  - Click Curto (>50ms): Confirmar / Avanzar menu.
  - Click Longo (>600ms): Voltar / Cancelar / Deter gravacion.
  - Dobre Click (<400ms): Menu de apagado rapido.
*/

#include <Wire.h>
#include <Adafruit_GFX.h>
#include <Adafruit_SH110X.h>
#include <Adafruit_INA219.h>
#include <SPI.h>
#include <SD.h>

// --- DEFINICIÓN DE PINS ---
#define PIN_SD_MOSI   0
#define PIN_MVBAT     1  
#define PIN_SD_MISO   2
#define PIN_SD_CS     3
#define PIN_MEDV      4  
#define PIN_ENC_B     5
#define PIN_REG_EN    6
#define PIN_ENC_A     7
#define PIN_STAT      8
#define PIN_ENC_S     9  
#define PIN_SD_CLK    10
#define PIN_SDA_I2C   20
#define PIN_SCL_I2C   21

#define OLED_ADDRESS  0x3C
#define SCREEN_WIDTH  128
#define SCREEN_HEIGHT 64

// --- CONSTANTES ---
const float V_OFFSET_ZERO = 0.021;
const float GANANCIA_REAL = 0.150;
const float FACTOR_CALIBRACION_BAT = 1.816;

// --- OBXECTOS ---
Adafruit_SH1106G pantalla = Adafruit_SH1106G(SCREEN_WIDTH, SCREEN_HEIGHT, &Wire, -1);
Adafruit_INA219 ina219(0x40);

enum EstadoApp {
  E_PRINCIPAL, E_MENU_ORIXE, E_MENU_HORAS, E_MENU_MINUTOS, 
  E_MENU_SEGUNDOS, E_MENU_METODO, E_MENU_VALOR, E_MENU_RESUMO, 
  E_GRAVANDO, E_FIN_GRAVACION, E_APAGAR
};
EstadoApp estadoActual = E_PRINCIPAL;

// --- VARIABLES DE CONFIGURACIÓN E CONTROL ---
int cfg_orixe = 0;   
int cfg_h = 0, cfg_m = 1, cfg_s = 0; 
int cfg_metodo = 0;  
int cfg_valor = 5;   

// --- VARIABLES DE GRAVACIÓN SD ---
File ficheiroDatos;
char nomeFicheiro[20];
uint32_t t_inicio_rec = 0;
uint32_t t_ultima_mostra = 0;
uint32_t intervalo_ms_rec = 0;
int max_puntos_rec = 0;
int puntos_gardados = 0;

// --- VARIABLES ENCODER ---
volatile int contadorEncoder = 0;
int ultimoEncoder = 0;

#define R_START     0x0
#define R_CW_FINAL  0x1
#define R_CW_BEGIN  0x2
#define R_CW_NEXT   0x3
#define R_CCW_BEGIN 0x4
#define R_CCW_FINAL 0x5
#define R_CCW_NEXT  0x6

const uint8_t ttable[7][4] = {
  {R_START,    R_CW_BEGIN,  R_CCW_BEGIN, R_START},           
  {R_CW_NEXT,  R_START,     R_CW_FINAL,  R_START | 0x10},    
  {R_CW_NEXT,  R_CW_BEGIN,  R_START,     R_START},           
  {R_CW_NEXT,  R_CW_BEGIN,  R_CW_FINAL,  R_START},           
  {R_CCW_NEXT, R_START,     R_CCW_BEGIN, R_START},           
  {R_CCW_FINAL, R_CCW_FINAL, R_START,     R_START | 0x20},    
  {R_CCW_NEXT, R_CCW_FINAL, R_CCW_BEGIN, R_START}            
};
volatile uint8_t estadoEncoderSM = R_START;

// --- VARIABLES BOTÓN ---
uint32_t t_press = 0, t_release = 0;
bool estadoBotAnterior = HIGH, esperandoDobreClick = false;
bool clickCurto = false, clickLongo = false, dobreClick = false;

// --- BUFFER DO OSCILOSCOPIO ---
float historicoGrafica[128]; 
uint32_t ultimoRefrescoGrafica = 0;
const int INTERVALO_GRAFICA = 50; 

// --- INTERRUPCIÓN ENCODER ---
void IRAM_ATTR lerEncoder() {
  uint8_t pinstate = (digitalRead(PIN_ENC_A) << 1) | digitalRead(PIN_ENC_B);
  estadoEncoderSM = ttable[estadoEncoderSM & 0x0F][pinstate];
  uint8_t resultado = estadoEncoderSM & 0x30;
  
  if (resultado == 0x10) contadorEncoder--; 
  else if (resultado == 0x20) contadorEncoder++; 
}

// Pantalla de instruccións
void mostrarBenvida() {
  pantalla.clearDisplay();
  pantalla.setTextSize(1);
  pantalla.setTextColor(SH110X_WHITE);
  pantalla.setCursor(20, 0);
  pantalla.print("XDeSIG  DATADEIRO");
  pantalla.setCursor(0, 18);
  pantalla.print("Xirar: Mover o menu");
  pantalla.setCursor(0, 30);
  pantalla.print("Click: Confirmar / SI");
  pantalla.setCursor(0, 42);
  pantalla.print("Longo: Voltar / NON");
  pantalla.setCursor(0, 55);
  pantalla.print("Dobre Cli: Apagado");
  pantalla.display();
  delay(2000); 
}


void setup() {
  Serial.begin(115200);
  
  pinMode(PIN_REG_EN, OUTPUT);
  digitalWrite(PIN_REG_EN, HIGH); 
  
  pinMode(PIN_STAT, INPUT_PULLDOWN);
  pinMode(PIN_ENC_S, INPUT); 
  pinMode(PIN_ENC_A, INPUT);
  pinMode(PIN_ENC_B, INPUT);
  
  attachInterrupt(digitalPinToInterrupt(PIN_ENC_A), lerEncoder, CHANGE);
  attachInterrupt(digitalPinToInterrupt(PIN_ENC_B), lerEncoder, CHANGE);

  Wire.begin(PIN_SDA_I2C, PIN_SCL_I2C);
  Wire.setClock(400000);
  pantalla.begin(OLED_ADDRESS, false);
  ina219.begin(&Wire);

  SPI.begin(PIN_SD_CLK, PIN_SD_MISO, PIN_SD_MOSI, PIN_SD_CS);
  SD.begin(PIN_SD_CS);

  for(int i=0; i<128; i++) historicoGrafica[i] = 0.0;

  mostrarBenvida();
  pantalla.clearDisplay();
  pantalla.setTextColor(SH110X_WHITE);
}

void lerBoton() {
  clickCurto = false; clickLongo = false; dobreClick = false;
  bool estadoBotActual = digitalRead(PIN_ENC_S);
  uint32_t agora = millis();

  if (estadoBotAnterior == HIGH && estadoBotActual == LOW) t_press = agora;
  
  if (estadoBotAnterior == LOW && estadoBotActual == HIGH) {
    t_release = agora;
    uint32_t duracion = t_release - t_press;

    if (duracion > 600) {
      clickLongo = true;
      esperandoDobreClick = false;
    } else if (duracion > 50) {
      if (esperandoDobreClick && (agora - t_press < 400)) {
        dobreClick = true;
        esperandoDobreClick = false;
      } else {
        esperandoDobreClick = true;
      }
    }
  }

  if (esperandoDobreClick && (agora - t_release > 250)) {
    clickCurto = true;
    esperandoDobreClick = false;
  }
  estadoBotAnterior = estadoBotActual;
}

void loop() {
  lerBoton();
  
  int deltaEncoder = contadorEncoder - ultimoEncoder;
  ultimoEncoder = contadorEncoder;

  if (estadoActual == E_PRINCIPAL || estadoActual == E_GRAVANDO) {
    if (millis() - ultimoRefrescoGrafica >= INTERVALO_GRAFICA) {
      ultimoRefrescoGrafica = millis();
      
      float novoValor = 0.0;
      if (cfg_orixe == 0) { 
        int rawMedv = analogRead(PIN_MEDV);
        float vMedvLocal = (rawMedv * 3.3) / 4095.0;
        novoValor = (vMedvLocal - V_OFFSET_ZERO) / GANANCIA_REAL; 
        if(novoValor < 0) novoValor = 0;
      } else { 
        novoValor = ina219.getCurrent_mA();
        if (isnan(novoValor)) novoValor = 0.0;
      }

      for (int i = 0; i < 127; i++) {
        historicoGrafica[i] = historicoGrafica[i + 1];
      }
      historicoGrafica[127] = novoValor;
    }
  }

  if (estadoActual == E_GRAVANDO) {
    if (millis() - t_ultima_mostra >= intervalo_ms_rec) {
      t_ultima_mostra = millis();
      
      float valorActual = historicoGrafica[127];
      if (ficheiroDatos) {
        ficheiroDatos.printf("%lu,%.3f\n", millis() - t_inicio_rec, valorActual);
        ficheiroDatos.flush(); 
      }
      
      puntos_gardados++;
      
      if (puntos_gardados >= max_puntos_rec) {
        if (ficheiroDatos) ficheiroDatos.close();
        estadoActual = E_FIN_GRAVACION;
      }
    }
  }

  switch (estadoActual) {
    case E_PRINCIPAL:
      if (clickCurto) estadoActual = E_MENU_ORIXE;
      if (dobreClick) estadoActual = E_APAGAR;
      break;

    case E_MENU_ORIXE:
      if (deltaEncoder > 0) cfg_orixe = 1;
      if (deltaEncoder < 0) cfg_orixe = 0;
      if (clickCurto) estadoActual = E_MENU_HORAS;
      if (clickLongo) estadoActual = E_PRINCIPAL;
      break;

    case E_MENU_HORAS:
      if (deltaEncoder != 0) {
        cfg_h += (deltaEncoder > 0) ? 1 : -1;
        if(cfg_h < 0) cfg_h = 0; if(cfg_h > 23) cfg_h = 23;
      }
      if (clickCurto) estadoActual = E_MENU_MINUTOS;
      if (clickLongo) estadoActual = E_PRINCIPAL;
      break;

    case E_MENU_MINUTOS:
      if (deltaEncoder != 0) {
        cfg_m += (deltaEncoder > 0) ? 1 : -1;
        if(cfg_m < 0) cfg_m = 0; if(cfg_m > 59) cfg_m = 59;
      }
      if (clickCurto) estadoActual = E_MENU_SEGUNDOS;
      if (clickLongo) estadoActual = E_MENU_HORAS;
      break;

    case E_MENU_SEGUNDOS:
      if (deltaEncoder != 0) {
        cfg_s += (deltaEncoder > 0) ? 1 : -1;
        if(cfg_s < 0) cfg_s = 0; if(cfg_s > 59) cfg_s = 59;
      }
      if (clickCurto) estadoActual = E_MENU_METODO;
      if (clickLongo) estadoActual = E_MENU_MINUTOS;
      break;

    case E_MENU_METODO:
      if (deltaEncoder > 0) cfg_metodo = 1;
      if (deltaEncoder < 0) cfg_metodo = 0;
      if (clickCurto) estadoActual = E_MENU_VALOR;
      if (clickLongo) estadoActual = E_MENU_SEGUNDOS;
      break;

    case E_MENU_VALOR:
      if (deltaEncoder != 0) {
        cfg_valor += (deltaEncoder > 0) ? 1 : -1;
        if(cfg_valor < 1) cfg_valor = 1;
      }
      if (clickCurto) estadoActual = E_MENU_RESUMO;
      if (clickLongo) estadoActual = E_MENU_METODO;
      break;

    case E_MENU_RESUMO:
      if (clickCurto) {
        if (!SD.begin(PIN_SD_CS)) {
          pantalla.clearDisplay();
          pantalla.drawRect(0, 10, 128, 44, SH110X_WHITE);
          pantalla.setCursor(12, 28);
          pantalla.print("ERRO: NON HAI SD");
          pantalla.display();
          delay(2000); 
          break; 
        }

        int total_segs = cfg_h * 3600 + cfg_m * 60 + cfg_s;
        if (cfg_metodo == 0) { 
          intervalo_ms_rec = cfg_valor * 1000UL;
          max_puntos_rec = (cfg_valor > 0) ? (total_segs / cfg_valor) : 0;
        } else { 
          max_puntos_rec = cfg_valor;
          intervalo_ms_rec = (cfg_valor > 0) ? ((total_segs * 1000UL) / cfg_valor) : 0;
        }

        int num = 1;
        snprintf(nomeFicheiro, sizeof(nomeFicheiro), "/DAT_%03d.CSV", num);
        while(SD.exists(nomeFicheiro) && num < 999) {
          num++;
          snprintf(nomeFicheiro, sizeof(nomeFicheiro), "/DAT_%03d.CSV", num);
        }

        ficheiroDatos = SD.open(nomeFicheiro, FILE_WRITE);
        if (ficheiroDatos) {
          ficheiroDatos.println(cfg_orixe == 0 ? "Tempo_ms,Diferencial_V" : "Tempo_ms,Corrente_mA");
        }

        puntos_gardados = 0;
        t_inicio_rec = millis();
        t_ultima_mostra = millis() - intervalo_ms_rec; 
        
        estadoActual = E_GRAVANDO;
      }
      if (clickLongo) estadoActual = E_MENU_VALOR;
      break;

    case E_GRAVANDO:
      if (clickLongo) {
        if (ficheiroDatos) ficheiroDatos.close();
        estadoActual = E_PRINCIPAL;
      }
      break;
      
    case E_FIN_GRAVACION:
      if (clickCurto || clickLongo) estadoActual = E_PRINCIPAL;
      break;

case E_APAGAR:
      if (clickCurto) {
        pantalla.clearDisplay();
        pantalla.setCursor(30, 20); 
        pantalla.print(" A Durmir!");
        pantalla.setCursor(5, 50); 
        pantalla.print("Rotar para despertar");
        pantalla.display();
        delay(3000);
        pantalla.clearDisplay();
        pantalla.display();
      
      // Enviamos o comando de apagado do xerador de tensión da pantalla
      Wire.beginTransmission(0x3C); 
      Wire.write(0x00); // 0x00 indica ao SH1106 que o seguinte é un comando
      Wire.write(0xAE); // Comando Display OFF
      Wire.endTransmission();
        
        // Creamos a máscara de bits para o GPIO 5 (1ULL << 5)
        uint64_t pin_mask = 1ULL << PIN_ENC_B; 
        
        // Activamos o espertar forzando o tipo de dato correcto para (LOW)
        // esperta o xirar o encoder
        esp_deep_sleep_enable_gpio_wakeup(pin_mask, (esp_deepsleep_gpio_wake_up_mode_t)0);

        // Entramos en Deep Sleep
        esp_deep_sleep_start();
      }
      if (clickLongo) estadoActual = E_PRINCIPAL;
      break;
  }

  debuxarPantalla();
  delay(5); 
}

// *** Icono Bateria ***
void debuxarBateriaPequena(int x, int y) {
  int rawBat = analogRead(PIN_MVBAT);
  float vBat = ((rawBat * 3.3) / 4095.0) * FACTOR_CALIBRACION_BAT;
  bool cargando = (digitalRead(PIN_STAT) == LOW);
  
  pantalla.drawRect(x, y, 12, 7, SH110X_WHITE);
  pantalla.fillRect(x+12, y+2, 1, 3, SH110X_WHITE);
  
  int nivel = map(vBat * 100, 340, 420, 0, 10);
  if (nivel < 0) nivel = 0; if (nivel > 10) nivel = 10;
  pantalla.fillRect(x+1, y+1, nivel, 5, SH110X_WHITE);
  
  if (cargando) {  
    pantalla.setCursor(x - 7, y - 1); 
    pantalla.print("+"); 
  }
}

void debuxarPantalla() {
  pantalla.clearDisplay();
  pantalla.setTextSize(1);
  
  if (estadoActual != E_APAGAR) debuxarBateriaPequena(114, 2);

  int total_segs = cfg_h * 3600 + cfg_m * 60 + cfg_s;
  int puntos_finais = (cfg_metodo == 0) ? ((cfg_valor > 0) ? (total_segs / cfg_valor) : 0) : cfg_valor;
  float intervalo_final = (cfg_metodo == 0) ? cfg_valor : ((cfg_valor > 0) ? ((float)total_segs / cfg_valor) : 0.0);
  float peso_estimado_kb = (puntos_finais * 25) / 1024.0; 

  switch (estadoActual) {
    
    case E_PRINCIPAL:
    case E_GRAVANDO:
     
     // --- 1. INFO SUPERIOR  ---
      pantalla.setTextSize(1);
      pantalla.setTextColor(SH110X_WHITE);
      
      if (cfg_orixe == 0) {
        float vActual = historicoGrafica[127];
        pantalla.setCursor(0, 0); 
        pantalla.printf("DIF:%.2fV", vActual);
        
        // Grade de puntos (cada 8px en horizontal)
        for (int v = 2; v <= 14; v += 2) {
          int yGrid = 63 - map(v * 100, 0, 1600, 0, 50); 
          for (int x = 0; x < 128; x += 8) pantalla.drawPixel(x, yGrid, SH110X_WHITE);
        }
        
        
        for (int i = 0; i < 127; i++) {
          int y1 = 63 - map(constrain(historicoGrafica[i], 0, 16) * 100, 0, 1600, 0, 50);
          int y2 = 63 - map(constrain(historicoGrafica[i+1], 0, 16) * 100, 0, 1600, 0, 50);
          pantalla.drawLine(i, y1, i+1, y2, SH110X_WHITE);
        }
      } 
      // --- 2. FONTE: SENSOR INA219 ---
      else {
        float vBus = ina219.getBusVoltage_V();
        float mAActual = historicoGrafica[127];
        pantalla.setCursor(0, 2); 
        pantalla.printf("%.1fV %.1fmA", vBus, mAActual);
        
        // Grade de puntos para INA219
        for (int ma = 200; ma <= 800; ma += 200) {
          int yGrid = 63 - map(ma, 0, 1000, 0, 50);
          for (int x = 0; x < 128; x += 8) pantalla.drawPixel(x, yGrid, SH110X_WHITE);
        }
        
        for (int i = 0; i < 127; i++) {
          int y1 = 63 - map(constrain(historicoGrafica[i], 0, 1000), 0, 1000, 0, 50);
          int y2 = 63 - map(constrain(historicoGrafica[i+1], 0, 1000), 0, 1000, 0, 50);
          pantalla.drawLine(i, y1, i+1, y2, SH110X_WHITE);
        }
      }
      
      // --- 3. INFORMACIÓN DE GRAVACIÓN (ZONA SUPERIOR CENTRAL) ---
      if (estadoActual == E_GRAVANDO) {
        
        // "REC" parpadea
        if ((millis() / 500) % 2 == 0) {
          pantalla.setCursor(0, 10);
          pantalla.print("REC");
        }
        
        // O progreso 
        pantalla.setCursor(66, 0);
        pantalla.printf("%d/%d", puntos_gardados, max_puntos_rec);
      }
      break;

// *** Textos dos Menús ***

    case E_MENU_ORIXE:
      pantalla.setCursor(0,0); pantalla.print("1. Sensor");
      pantalla.setCursor(10, 22); pantalla.printf("%s Amp diferencial", (cfg_orixe == 0) ? ">" : " ");
      pantalla.setCursor(10, 36); pantalla.printf("%s Sens. INA219", (cfg_orixe == 1) ? ">" : " ");
      break;

    case E_MENU_HORAS:
    case E_MENU_MINUTOS:
    case E_MENU_SEGUNDOS:
      pantalla.setCursor(0,0); pantalla.print("2. Tempo total");
      pantalla.setTextSize(2);
      pantalla.setCursor(16, 26);
      pantalla.printf("%02d:%02d:%02d", cfg_h, cfg_m, cfg_s);
      pantalla.setTextSize(1); 
      if(estadoActual == E_MENU_HORAS)   pantalla.drawFastHLine(16, 43, 22, SH110X_WHITE);
      if(estadoActual == E_MENU_MINUTOS) pantalla.drawFastHLine(52, 43, 22, SH110X_WHITE);
      if(estadoActual == E_MENU_SEGUNDOS) pantalla.drawFastHLine(88, 43, 22, SH110X_WHITE);
      break;

    case E_MENU_METODO:
      pantalla.setCursor(0,0); pantalla.print("3. Mostraxe x ");
      pantalla.setCursor(15, 24); pantalla.printf("%s Intervalo", (cfg_metodo == 0) ? ">" : " ");
      pantalla.setCursor(15, 38); pantalla.printf("%s Puntos", (cfg_metodo == 1) ? ">" : " ");
      break;

    case E_MENU_VALOR:
      pantalla.setCursor(0,0); pantalla.print(cfg_metodo == 0 ? "4. Intervalo" : "4. Puntos");
      pantalla.setTextSize(2);
      pantalla.setCursor(30, 24); pantalla.printf("%d %s", cfg_valor, (cfg_metodo == 0) ? "Seg" : "Pts");
      pantalla.setTextSize(1);
      break;

    case E_MENU_RESUMO:
      pantalla.setCursor(0,0);  pantalla.print("5. Resumo");
      pantalla.setCursor(0,10); pantalla.printf("Fonte:  %s", (cfg_orixe == 0) ? "Amp Diferenc." : "INA219");
      pantalla.setCursor(0,19); pantalla.printf("Tempo:  %02d:%02d:%02d", cfg_h, cfg_m, cfg_s);
      pantalla.setCursor(0,28); pantalla.printf("Interv: %.1f Seg", intervalo_final);
      pantalla.setCursor(0,37); pantalla.printf("Puntos: %d", puntos_finais);
      pantalla.setCursor(0,46); pantalla.printf("Tamanno:%.2f KB", peso_estimado_kb);
      pantalla.setCursor(0,55); pantalla.print("> CLICK CONFIRMA");
      break;

    // *** PANTALLA FIN DE GRAVACIÓN ***
    case E_FIN_GRAVACION:
      pantalla.drawRoundRect(2, 2, 124, 60, 4, SH110X_WHITE); 
      pantalla.setCursor(16, 8); pantalla.print("CAPTURA REMATADA");
      pantalla.drawFastHLine(16, 17, 96, SH110X_WHITE);
      
      pantalla.setCursor(10, 26); 
      pantalla.printf("Fich: %s", nomeFicheiro + 1);
      pantalla.setCursor(10, 38); 
      pantalla.printf("Pts Gardados: %d", puntos_gardados);
      
      pantalla.fillRect(10, 48, 108, 12, SH110X_WHITE);
      pantalla.setTextColor(SH110X_BLACK);
      pantalla.setCursor(15, 50); pantalla.print("> CLICK PARA SAIR");
      pantalla.setTextColor(SH110X_WHITE); 
      break;

    case E_APAGAR:
      pantalla.setCursor(10, 15); pantalla.print(" Apagar sistema?");
      pantalla.setCursor(0, 42); pantalla.print("[Click] Si [Long] Non");
      break;
  }
  pantalla.display();
}

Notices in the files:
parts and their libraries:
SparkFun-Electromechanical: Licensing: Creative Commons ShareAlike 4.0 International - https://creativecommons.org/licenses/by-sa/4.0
